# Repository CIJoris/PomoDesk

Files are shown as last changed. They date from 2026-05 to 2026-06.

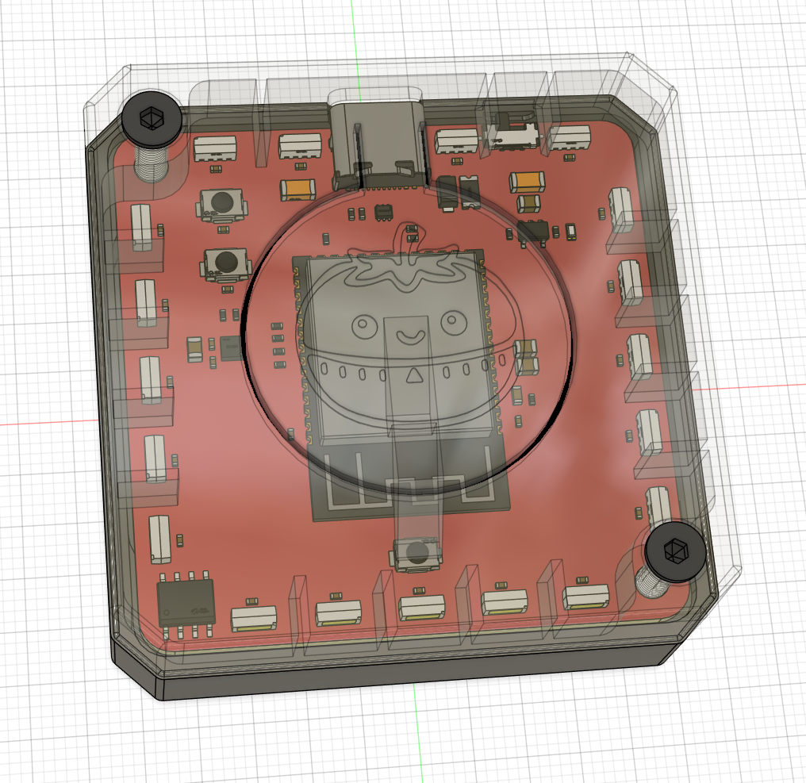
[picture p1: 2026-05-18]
Hardware/Enclosure/Fusion360_XVKBeL06ep.png

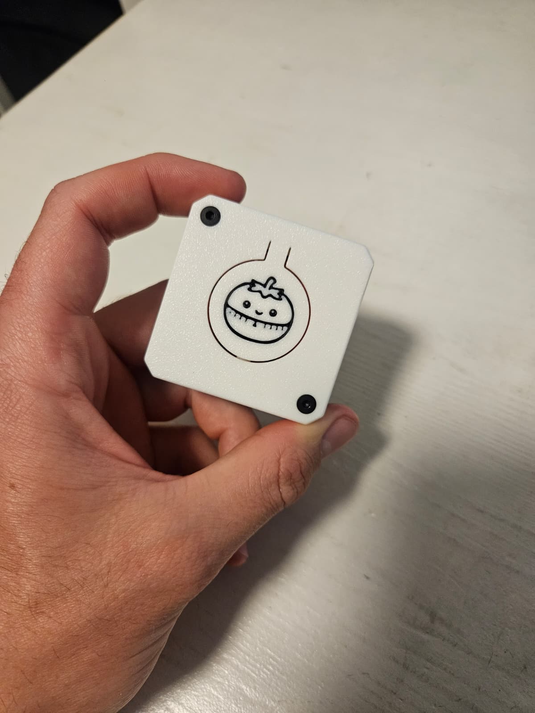
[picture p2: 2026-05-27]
Photos/pomo-desk-hand.jpeg

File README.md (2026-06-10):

# PomoDesk - Physical Pomodoro Timer

pomo-desk-banner-image

**ESP32-based physical Pomodoro timer with local configuration options**

Designing PCB's, creating or adjusting schematics, doing layout, all these tasks put me in this trance, this FLOW, as some would say.
I've learned it's a gift, not available for everyone, to reach this kind of state. But, there is a small downside to this. This flow-state you have to manage with caution.

To not forget about life, you need something to wake you from this flow every now and then.
The perfect way to do this, for me personally, is to have a Pomodoro timer.

**Focus for 45 minutes, break for 5, then continue.**

WhatsApp Image 2026-05-29 at 22 05 28

I wanted to create a Pomodoro timer that's not some app counting down on my screen.
It needs to be physical, elegant and as unobtrusive as possible, only showing itself when it's time to break.

**States & Workflow**

PomoDesk follows the Pomodoro technique: a simple productivity method that alternates periods of focused work with short breaks to help maintain concentration and prevent burnout.

The device has three states:

* Idle (Orange) – Ready to start a new session.
* Focus (Green) – A dedicated work period where distractions are minimized and attention stays on a single task.
* Break (Red) – A short recovery period to step away, stretch, grab a drink, or simply reset before the next focus session.

WhatsApp Image 2026-05-30 at 12 02 46

By default, PomoDesk uses a 45-minute focus period followed by a 5-minute break, after which it returns to Idle and waits for the next session. All timings can be customized through the built-in configuration webserver.

**Power**

PomoDesk is powered through a standard USB-C connection and is designed to run continuously on any 5V USB power source.

WhatsApp Image 2026-05-29 at 22 11 27 

It can be powered from:

* A USB wall adapter
* A laptop or desktop USB port
* A USB hub or monitor with USB output
* A power bank for portable use

The ESP32-S3 and LED ring have been optimized for low power consumption, and the built-in ECO mode and deep sleep functionality help minimize energy usage when the device is idle.

This first iteration is far from perfect, but it's a start.

pomo-desk-orange

---

# V1.1 - Local Configuration Webserver

Version 1.1 adds a local configuration mode directly on the ESP32-S3.

By pressing and holding the button, PomoDesk can start its own Wi-Fi configuration portal. From there, the timer can be customized without needing to reflash the firmware.

### Button controls

WhatsApp Image 2026-05-31 at 11 31 27

* Short press: step through states
* Hold 1.5 seconds, release: enter or exit config mode
* Hold 3 seconds, release: toggle RGB cycle mode
* Hold 6 seconds, release: go to sleep

### Config mode

When config mode is active, PomoDesk creates its own Wi-Fi network:

```text
Wi-Fi: PomoDesk-Config
Password: pomodesk
Open: http://pomodesk.local
Fallback: http://10.10.10.1
```

### Added in v1.1 
* Local Wi-Fi configuration webserver
* Adjustable state colors
* Adjustable Focus, Break and Idle timings
* Multiple LED transition modes
* Adjustable transition speed
* Brightness control
* RGB cycle mode
* ECO brightness mode
* Reset to default settings
* Config mode with blue LED indication
* Deep sleep mode
* Wake-up by button press
* Settings saved to ESP32 memory

---

*Feel free to send me constructive criticism or things you would like me to implement, or even if you would like to help me develop this system!*

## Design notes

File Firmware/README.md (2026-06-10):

# PomoDesk - Physical Pomodoro Timer
**ESP32-based Pomodoro timer with API options**

## Getting Started

### Requirements

Before compiling and uploading the firmware, make sure the following is installed:

* Arduino IDE 2.x
* Adafruit NeoPixel library
* ESP32 Boards Package by Espressif Systems

### Install ESP32 Board Support

In Arduino IDE:

1. Open **File → Preferences**
2. Add the following URL to **Additional Boards Manager URLs**:

```text
https://espressif.github.io/arduino-esp32/package_esp32_index.json
```

3. Open **Tools → Board → Boards Manager**
4. Search for **ESP32**
5. Install **ESP32 by Espressif Systems**

### Install Required Libraries

Open **Tools → Manage Libraries** and install:

* Adafruit NeoPixel

### Board Configuration

Select the following settings before uploading:

* Board: **ESP32S3 Dev Module**
* USB CDC On Boot: **Enabled**
* Upload Mode: **UART0 / Default**
* Flash Mode: **QIO 80MHz**
* Partition Scheme: **Default 4MB with SPIFFS** (or larger if desired)

### Uploading

1. Connect the ESP32-S3 via USB-C.
2. Select the correct COM port in Arduino IDE.
3. Compile and upload the firmware.
4. Open the Serial Monitor if debugging is required.

After flashing, the device will boot directly into the **Idle** state and is ready to use.

# V1.0:

## Features

- Physical one-button control
- Idle, Focus, Break states
- Multiple LED transition modes
- Settings saved in ESP32 Preferences memory

# V1.1:

**Now with a configurable NeoPixel LED ring and a built-in local configuration webserver.**

## Features

- Config state
- Adjustable state colors
- Adjustable Focus, Break, and Idle times
- Adjustable transition speed
- Brightness control with ECO mode
- RGB cycle mode
- Local Wi-Fi configuration portal
- Deep sleep mode with button wake-up

## Controls

- Short press: step through states
- Hold 1.5 seconds, release: enter or exit config mode
- Hold 3 seconds, release: toggle RGB cycle mode
- Hold 6 seconds, release: go to sleep

## States

PomoDesk follows the Pomodoro technique: alternating focused work sessions with short breaks to maintain concentration and prevent mental fatigue.

The device has three primary states:

* **Idle (Orange)** – Ready to start a new session.
* **Focus (Green)** – Active work period.
* **Break (Red)** – Short recovery period.

By default, PomoDesk uses a **45-minute Focus session** followed by a **5-minute Break**. These timings can be customized through the configuration webserver in V1.1.

## Config Mode

When config mode is active, PomoDesk creates its own Wi-Fi network:

- Wi-Fi: `PomoDesk-Config`
- Password: `pomodesk`
- Open: `http://pomodesk.local`
- Fallback: `http://10.10.10.1`

The web interface lets you customize colors, timers, transitions, speed, brightness, reset defaults, exit config mode, or put the device to sleep.

---

*Feel free to send me constructive criticism or things you would like me to implement, or even if you would like to help me develop this system!*

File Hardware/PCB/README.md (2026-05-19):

# PomoDesk - Physical Pomodoro Timer
**ESP32-based Pomodoro timer with API options**

V1.0 notes:
---

- the whole board is getting a bit warm
- on/off button is hard to reach, might as well remove
- data pin for LEDs needs to be higher voltage, use a levelshifter like: 74AHCT1G125, 74AHCT125, SN74AHCT1G125, SN74AHCT125
- power led connected to IO18 is not standard ON so the pin must be high/mid when the ESP is not programmed
- the corners don't have LEDs, which is not pretty
- startup surge causes USB hub to disconnect shortly -> Add LED power switching:
USB 5V → P-MOSFET/load switch → LED 5V
ESP GPIO → enable LED power after boot 

---

*Feel free to send me constructive criticism or things you would like me to implement, or even if you would like to help me develop this system!*

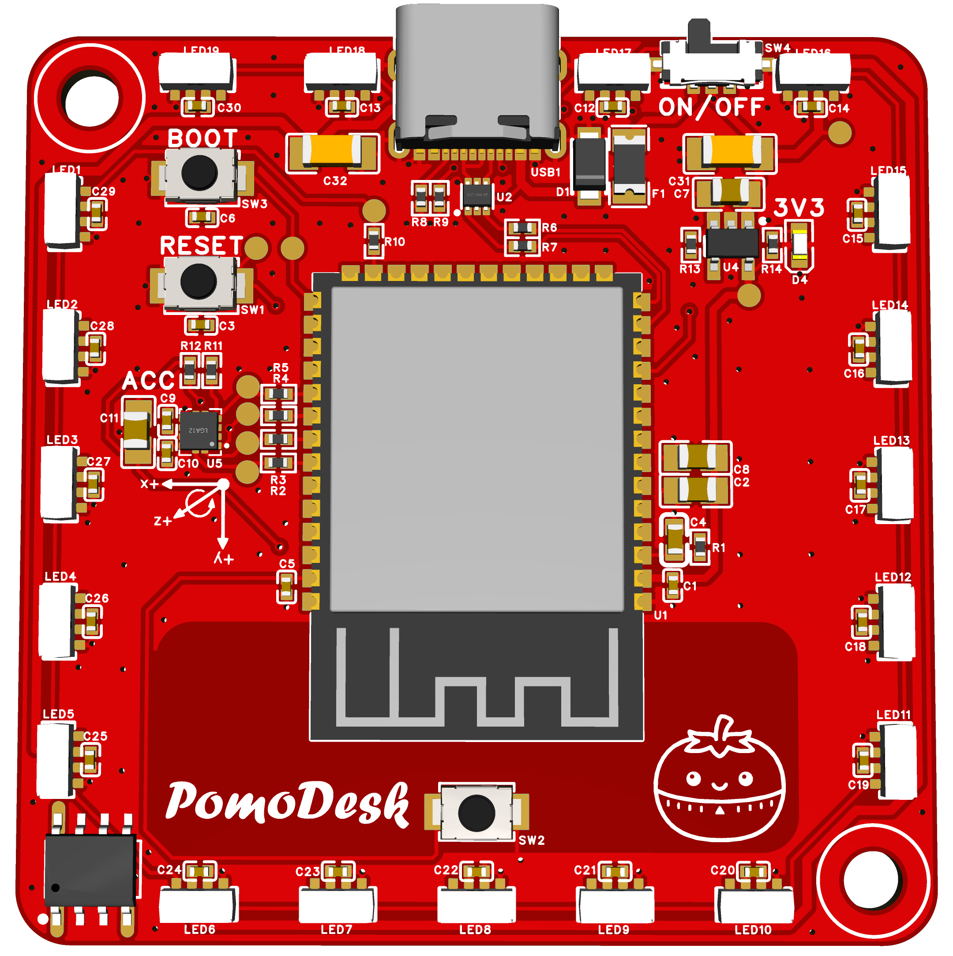
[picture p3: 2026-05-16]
Hardware/PCB/3D_PCB_V1.0_2026-05-16-top.png

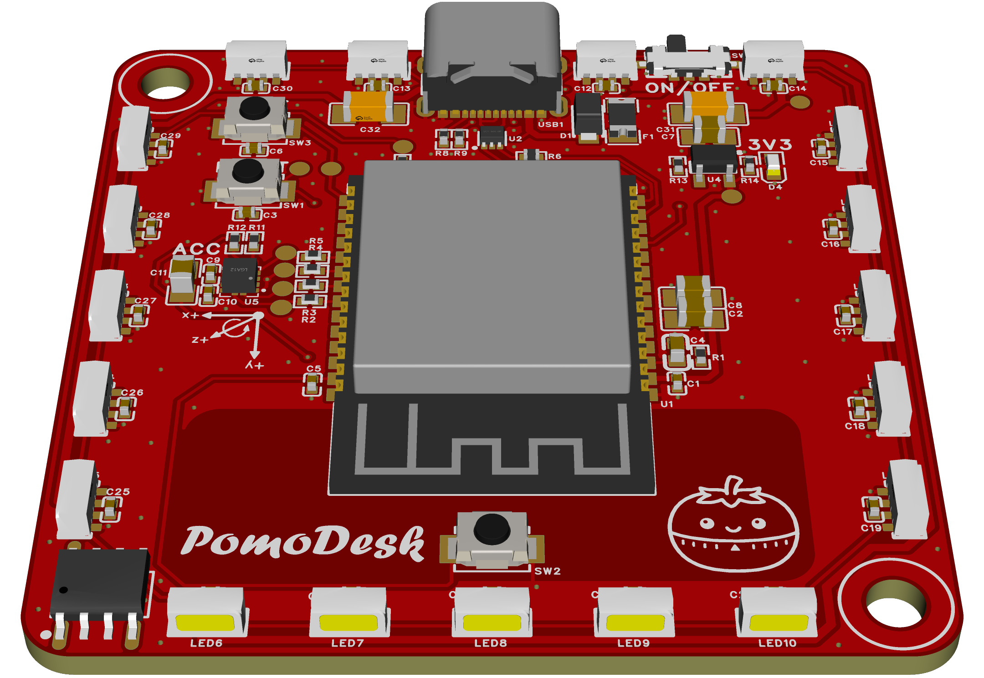
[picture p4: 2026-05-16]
Hardware/PCB/3D_PCB_V1.0_2026-05-16.png

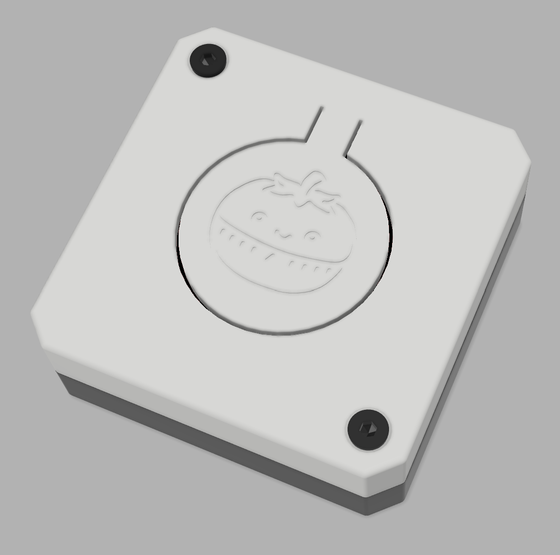
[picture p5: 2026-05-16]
Hardware/Enclosure/pomodesk-render-v1.0.png

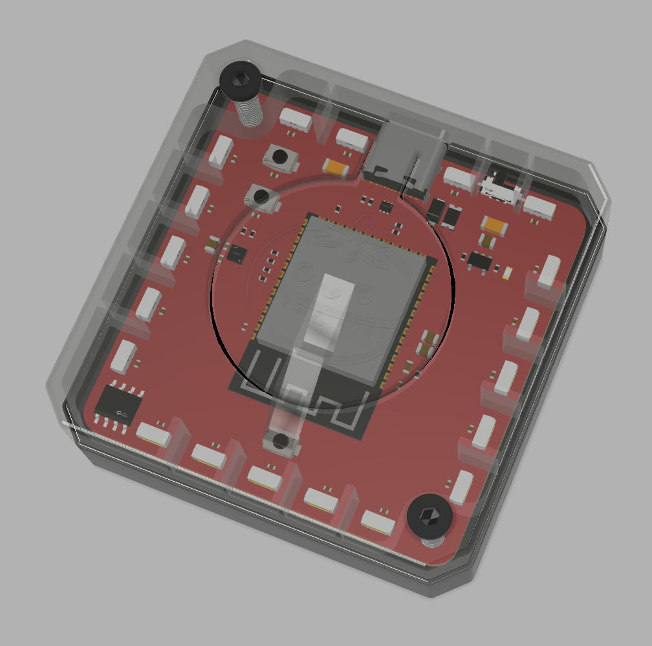
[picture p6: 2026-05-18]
Hardware/Enclosure/Fusion360_l14pNBqwwQ.png

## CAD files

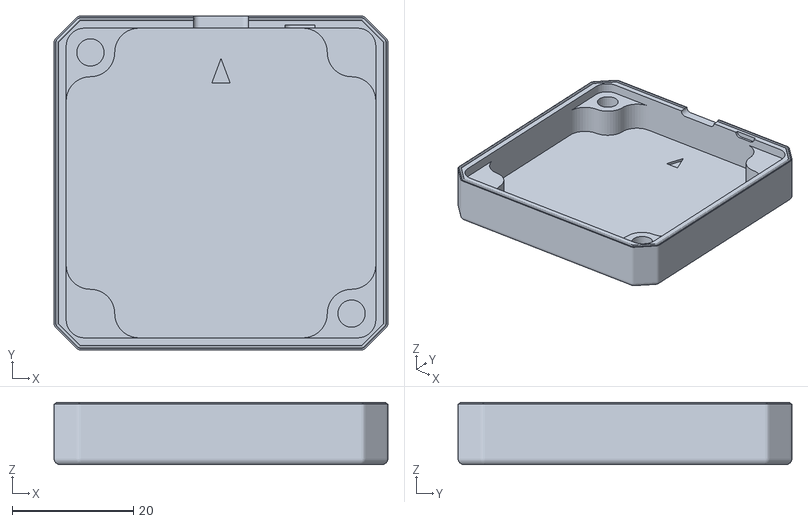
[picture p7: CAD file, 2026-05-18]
Hardware/Enclosure/pomo-desk-bottom-v4.stl
55.0 x 55.0 x 10.2

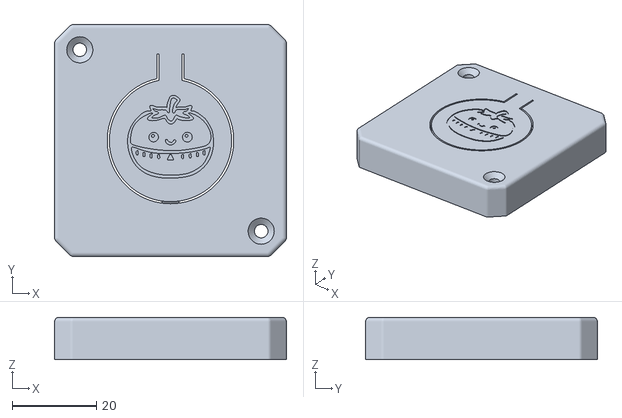
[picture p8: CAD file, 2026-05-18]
Hardware/Enclosure/pomo-desk-top-v4.stl
55.0 x 55.0 x 10.0

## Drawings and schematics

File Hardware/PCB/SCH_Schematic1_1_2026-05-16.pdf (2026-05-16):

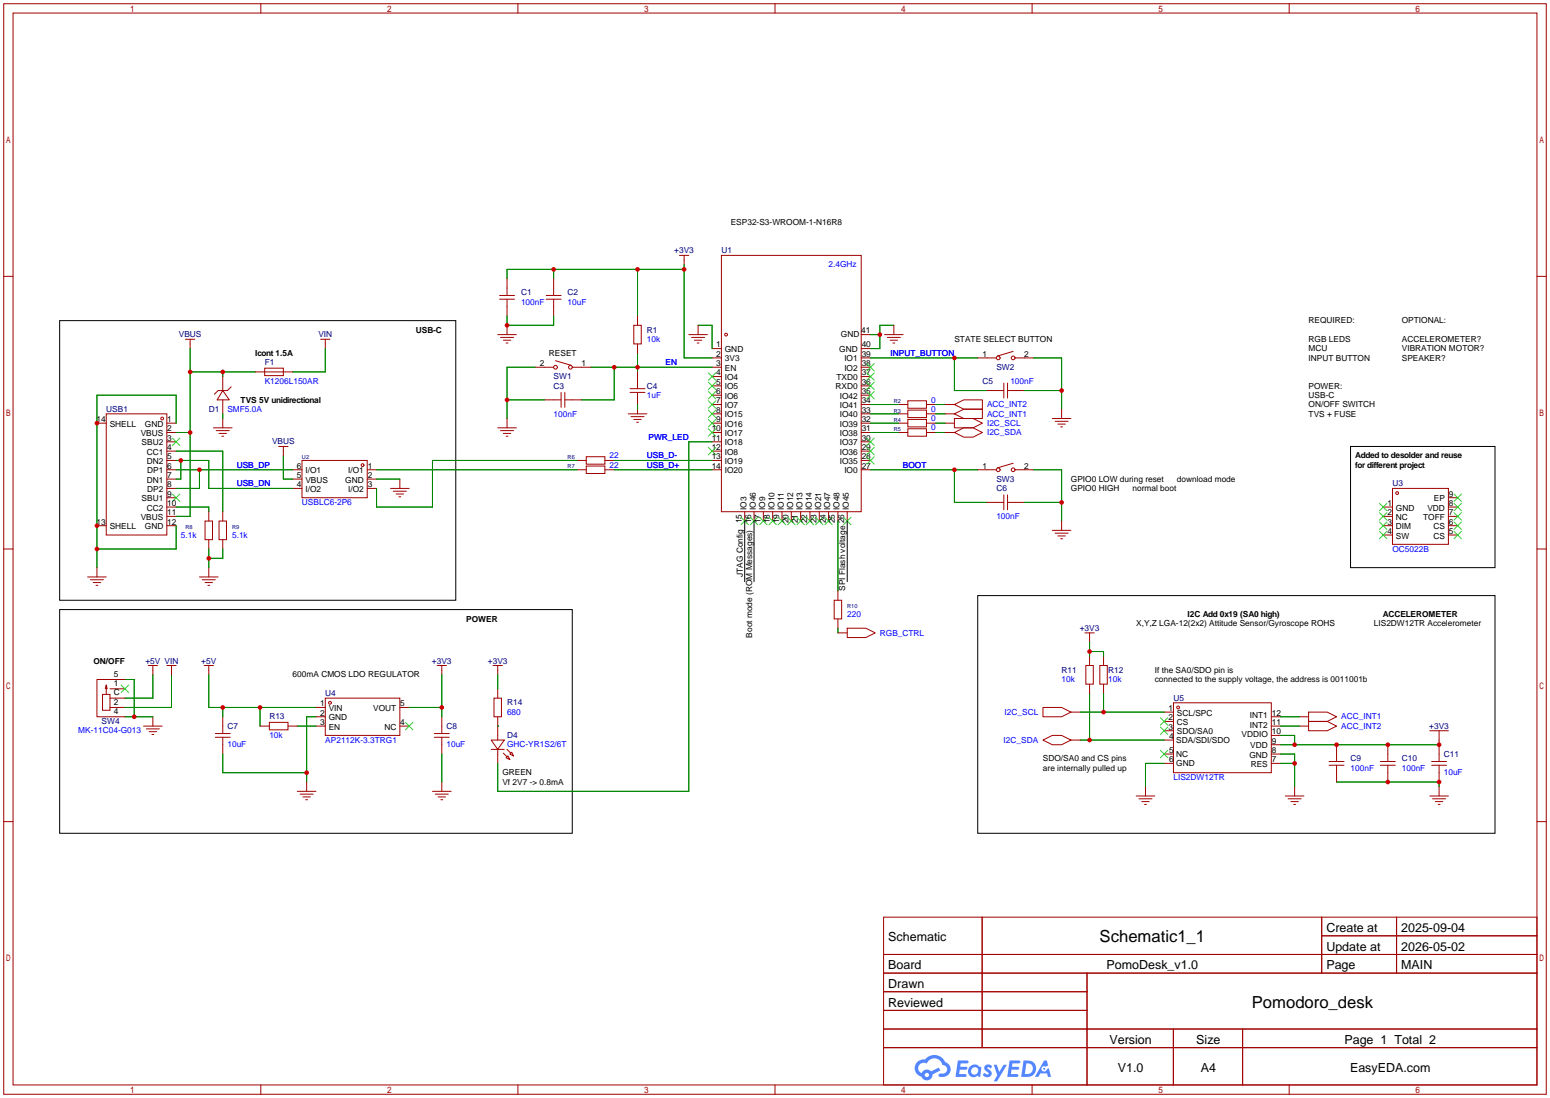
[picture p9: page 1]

Added to desolder and reuse
for different project

GPIO0 LOW during reset download mode
GPIO0 HIGH normal boot

Boot mode (ROM Messages)

X,Y,Z LGA-12(2x2) Attitude Sensor/Gyroscope ROHS

If the SA0/SDO pin is
connected to the supply voltage, the address is 0011001b
SCL/SPC 1
SDO/SA0 3
SDA/SDI/SDO 4
GND 6
LIS2DW12TR

SDO/SA0 and CS pins
are internally pulled up

Schematic | Schematic1_1 | Create at | 2025-09-04

Update at | 2026-05-02

Board | PomoDesk_v1.0 | Page | MAIN
Drawn | | Pomodoro_desk
Reviewed

Version | Size | Page 1 Total 2
V1.0 | A4 | EasyEDA.com

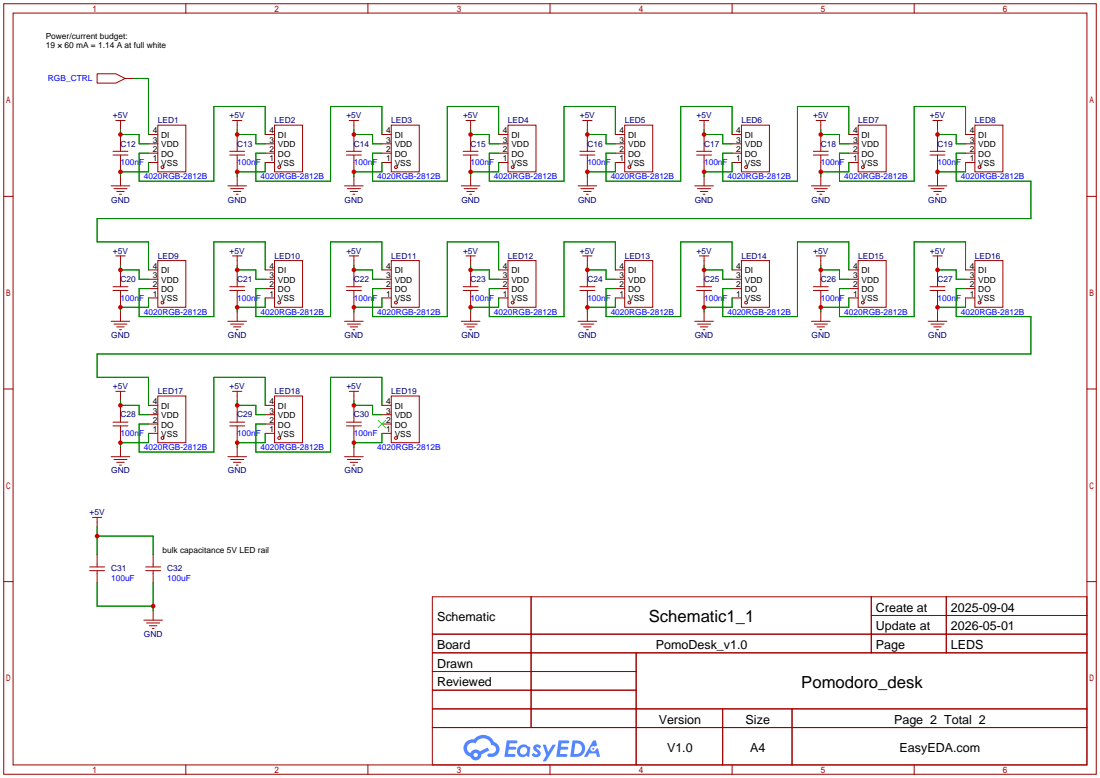
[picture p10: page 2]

Power/current budget:
19 × 60 mA = 1.14 A at full white

Schematic | Schematic1_1 | Create at | 2025-09-04

Update at | 2026-05-01

Board | PomoDesk_v1.0 | Page | LEDS
Drawn | | Pomodoro_desk
Reviewed

Version | Size | Page 2 Total 2
V1.0 | A4 | EasyEDA.com

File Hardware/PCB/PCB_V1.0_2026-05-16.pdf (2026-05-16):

# BOOT

# ON/OFF

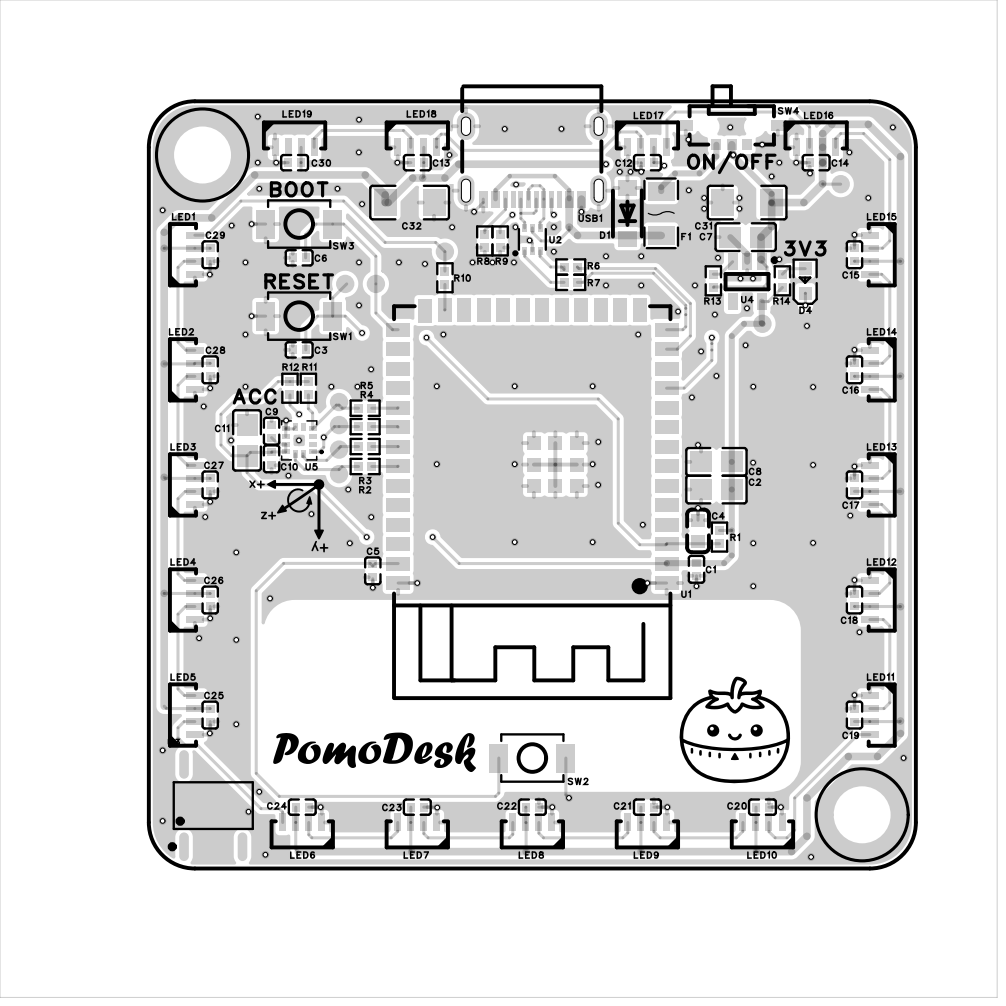
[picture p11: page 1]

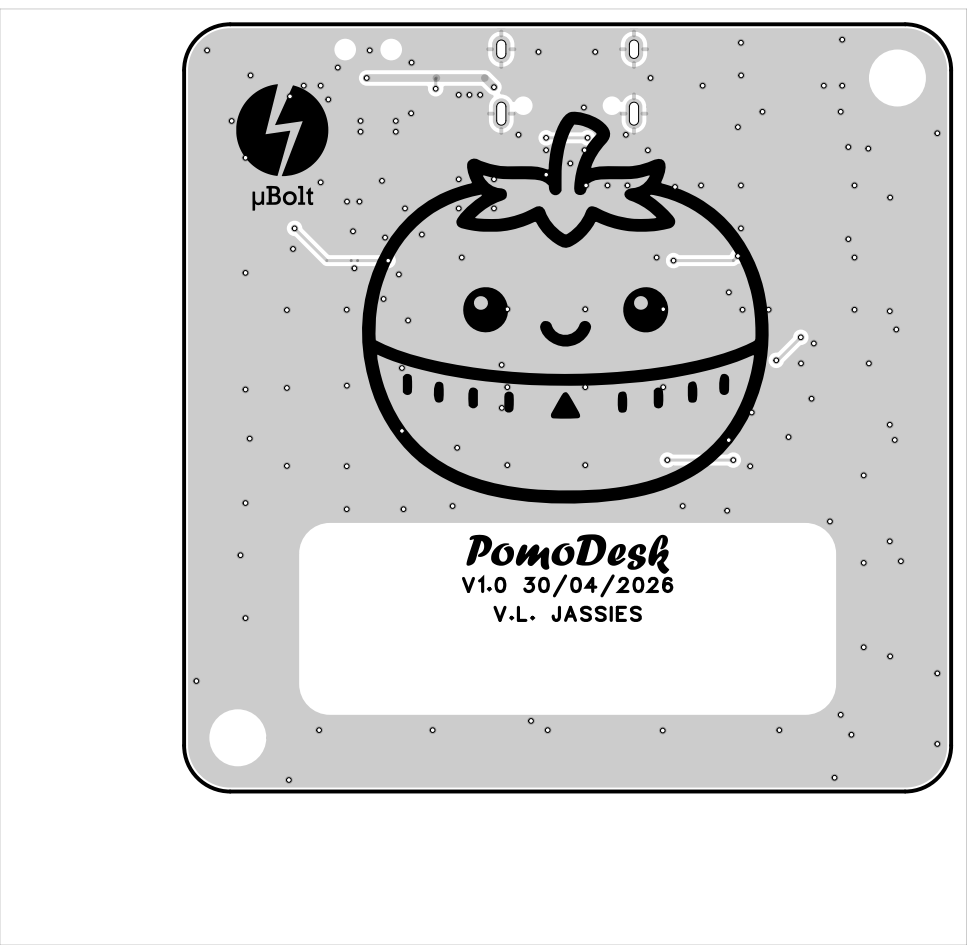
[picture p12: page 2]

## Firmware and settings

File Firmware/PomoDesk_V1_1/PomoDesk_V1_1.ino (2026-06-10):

#include <Arduino.h>
#include <Adafruit_NeoPixel.h>
#include <WiFi.h>
#include <WebServer.h>
#include <Preferences.h>
#include <DNSServer.h>
#include <ESPmDNS.h>
#include <esp_bt.h>
#include <esp_sleep.h>
#include <driver/rtc_io.h>

// --- Pins ---
const int BTN_STATE = 1;
const int LED_DATA  = 48;
const int PWR_LED   = 18;

// --- LEDs ---
const int NUM_LEDS = 19;
Adafruit_NeoPixel strip(NUM_LEDS, LED_DATA, NEO_GRB + NEO_KHZ800);

// --- WiFi / Webserver ---
WebServer server(80);
DNSServer dnsServer;
Preferences prefs;

const char* AP_SSID = "PomoDesk-Config";
const char* AP_PASS = "pomodesk";

IPAddress apIP(10, 10, 10, 1);
IPAddress gateway(10, 10, 10, 1);
IPAddress subnet(255, 255, 255, 0);

bool configMode = false;

// --- Defaults ---
const uint32_t WORK_MS_DEFAULT     = 45UL * 60UL * 1000UL;
const uint32_t BREAK_MS_DEFAULT    = 5UL  * 60UL * 1000UL;
const uint32_t IDLE_LED_MS_DEFAULT = 10UL * 60UL * 1000UL;

const uint32_t CONFIG_TIME_MS  = 1500;
const uint32_t RAINBOW_TIME_MS = 3000;
const uint32_t OFF_TIME_MS     = 6000;

const uint32_t DEFAULT_IDLE_RAW   = 0xFF5000;
const uint32_t DEFAULT_WORK_RAW   = 0x00FF00;
const uint32_t DEFAULT_BREAK_RAW  = 0xFF0000;
const uint32_t DEFAULT_CONFIG_RAW = 0x0078FF;

// --- Settings ---
uint32_t workMs;
uint32_t breakMs;
uint32_t idleLedMs;
uint8_t brightness = 150;

// --- Transitions ---
enum Transition {
  SET_RING,
  RUNNING_LIGHT,
  RUNNING_FILL,
  RUNNING_LIGHT_CLEAR,
  FADE
};

Transition transition = RUNNING_FILL;
uint16_t transitionDelayMs = 40;

// --- States ---
enum State { IDLE, WORK, BREAK };
State state = IDLE;

uint32_t stateStartMs = 0;
bool idleLedsOff = false;
bool rainbowMode = false;
uint8_t rainbowOffset = 0;
uint32_t lastRainbowStepMs = 0;

// --- Colors ---
uint32_t COLOR_IDLE;
uint32_t COLOR_WORK;
uint32_t COLOR_BREAK;
uint32_t COLOR_CONFIG;

uint32_t currentColor = 0;

// --- Forward declarations ---
void stopConfigServer();
void powerOffDevice();
void handleExitConfig();
void handleSleep();
void startRainbowMode();
void stopRainbowMode();

// --- Helpers ---
uint32_t rawToNeo(uint32_t raw) {
  uint8_t r = (raw >> 16) & 0xFF;
  uint8_t g = (raw >> 8) & 0xFF;
  uint8_t b = raw & 0xFF;
  return strip.Color(r, g, b);
}

String colorToHex(uint32_t color) {
  char hex[8];
  sprintf(hex, "#%02X%02X%02X",
          (uint8_t)(color >> 16),
          (uint8_t)(color >> 8),
          (uint8_t)color);
  return String(hex);
}

uint32_t hexToColor(String hex) {
  hex.replace("#", "");
  uint32_t value = strtoul(hex.c_str(), nullptr, 16);
  return rawToNeo(value);
}

uint16_t transitionDelay() {
  return constrain(transitionDelayMs, 5, 500);
}

uint32_t wheel(uint8_t wheelPos) {
  wheelPos = 255 - wheelPos;

  if (wheelPos < 85) {
    return strip.Color(255 - wheelPos * 3, 0, wheelPos * 3);
  }

  if (wheelPos < 170) {
    wheelPos -= 85;
    return strip.Color(0, wheelPos * 3, 255 - wheelPos * 3);
  }

  wheelPos -= 170;
  return strip.Color(wheelPos * 3, 255 - wheelPos * 3, 0);
}

// --- LED functions ---
void setRing(uint32_t color) {
  strip.setBrightness(brightness);

  for (int i = 0; i < NUM_LEDS; i++) {
    strip.setPixelColor(i, color);
  }

  strip.show();
  currentColor = color;
}

void allLedsOff() {
  strip.clear();
  strip.show();
  currentColor = 0;
}

void runningLights(uint32_t color) {
  allLedsOff();

  for (int i = 0; i < NUM_LEDS; i++) {
    strip.clear();
    strip.setPixelColor(i, color);
    strip.setPixelColor((i - 1 + NUM_LEDS) % NUM_LEDS, color);
    strip.setPixelColor((i - 2 + NUM_LEDS) % NUM_LEDS, color);
    strip.show();
    delay(transitionDelay());
  }

  setRing(color);
}

void runningFill(uint32_t color) {
  allLedsOff();

  for (int i = 0; i < NUM_LEDS; i++) {
    strip.setPixelColor(i, color);
    strip.show();
    delay(transitionDelay());
  }

  currentColor = color;
}

void runningFillClear(uint32_t color) {
  runningFill(color);
  delay(transitionDelay());

  for (int i = 0; i < NUM_LEDS; i++) {
    strip.setPixelColor(i, 0);
    strip.show();
    delay(transitionDelay());
  }

  currentColor = 0;
}

uint8_t blend8(uint8_t from, uint8_t to, uint8_t step, uint8_t steps) {
  return from + ((int16_t)(to - from) * step) / steps;
}

void fadeToColor(uint32_t targetColor) {
  uint8_t r1 = (currentColor >> 16) & 0xFF;
  uint8_t g1 = (currentColor >> 8) & 0xFF;
  uint8_t b1 = currentColor & 0xFF;

  uint8_t r2 = (targetColor >> 16) & 0xFF;
  uint8_t g2 = (targetColor >> 8) & 0xFF;
  uint8_t b2 = targetColor & 0xFF;

  const uint8_t fadeSteps = 40;

  for (uint8_t step = 0; step <= fadeSteps; step++) {
    uint32_t c = strip.Color(
      blend8(r1, r2, step, fadeSteps),
      blend8(g1, g2, step, fadeSteps),
      blend8(b1, b2, step, fadeSteps)
    );

    for (int i = 0; i < NUM_LEDS; i++) {
      strip.setPixelColor(i, c);
    }

    strip.show();
    delay(transitionDelay());
  }

  currentColor = targetColor;
}

void applyTransition(uint32_t color) {
  strip.setBrightness(brightness);

  switch (transition) {
    case SET_RING:
      setRing(color);
      break;

    case RUNNING_LIGHT:
      runningLights(color);
      break;

    case RUNNING_FILL:
      runningFill(color);
      break;

    case RUNNING_LIGHT_CLEAR:
      runningFillClear(color);
      break;

    case FADE:
      fadeToColor(color);
      break;
  }
}

void updateRainbowCycle() {
  const uint32_t now = millis();

  if (now - lastRainbowStepMs < 30) {
    return;
  }

  lastRainbowStepMs = now;
  strip.setBrightness(brightness);

  for (int i = 0; i < NUM_LEDS; i++) {
    uint8_t wheelPos = (i * 256 / NUM_LEDS + rainbowOffset) & 0xFF;
    strip.setPixelColor(i, wheel(wheelPos));
  }

  strip.show();
  rainbowOffset++;
}

// --- Settings ---
void loadSettings() {
  prefs.begin("pomodesk", true);

  workMs = prefs.getUInt("workMs", WORK_MS_DEFAULT);
  breakMs = prefs.getUInt("breakMs", BREAK_MS_DEFAULT);
  idleLedMs = prefs.getUInt("idleMs", IDLE_LED_MS_DEFAULT);

  brightness = prefs.getUChar("bright", 150);
  transitionDelayMs = prefs.getUShort("delay", 40);
  transition = (Transition)prefs.getUChar("trans", RUNNING_FILL);

  COLOR_IDLE   = prefs.getUInt("idleColor", rawToNeo(DEFAULT_IDLE_RAW));
  COLOR_WORK   = prefs.getUInt("workColor", rawToNeo(DEFAULT_WORK_RAW));
  COLOR_BREAK  = prefs.getUInt("breakColor", rawToNeo(DEFAULT_BREAK_RAW));
  COLOR_CONFIG = prefs.getUInt("configColor", rawToNeo(DEFAULT_CONFIG_RAW));

  prefs.end();
}

void saveSettings() {
  prefs.begin("pomodesk", false);

  prefs.putUInt("workMs", workMs);
  prefs.putUInt("breakMs", breakMs);
  prefs.putUInt("idleMs", idleLedMs);

  prefs.putUChar("bright", brightness);
  prefs.putUShort("delay", transitionDelayMs);
  prefs.putUChar("trans", transition);

  prefs.putUInt("idleColor", COLOR_IDLE);
  prefs.putUInt("workColor", COLOR_WORK);
  prefs.putUInt("breakColor", COLOR_BREAK);
  prefs.putUInt("configColor", COLOR_CONFIG);

  prefs.end();
}

void resetSettings() {
  workMs = WORK_MS_DEFAULT;
  breakMs = BREAK_MS_DEFAULT;
  idleLedMs = IDLE_LED_MS_DEFAULT;

  brightness = 150;
  transitionDelayMs = 40;
  transition = RUNNING_FILL;

  COLOR_IDLE   = rawToNeo(DEFAULT_IDLE_RAW);
  COLOR_WORK   = rawToNeo(DEFAULT_WORK_RAW);
  COLOR_BREAK  = rawToNeo(DEFAULT_BREAK_RAW);
  COLOR_CONFIG = rawToNeo(DEFAULT_CONFIG_RAW);

  saveSettings();
}

// --- State logic ---
void enterState(State s) {
  if (configMode) return;

  rainbowMode = false;

  state = s;
  stateStartMs = millis();
  idleLedsOff = false;

  if (state == IDLE) {
    applyTransition(COLOR_IDLE);
  }
  else if (state == WORK) {
    applyTransition(COLOR_WORK);
  }
  else if (state == BREAK) {
    applyTransition(COLOR_BREAK);
  }
}

void nextState() {
  if (configMode) return;

  if (state == IDLE) {
    enterState(WORK);
  }
  else if (state == WORK) {
    enterState(BREAK);
  }
  else {
    enterState(IDLE);
  }
}

// --- Web UI ---
String htmlPage() {
  String html = R"rawliteral(
<!DOCTYPE html>
<html>
<head>
<meta name="viewport" content="width=device-width, initial-scale=1">
<title>PomoDesk Config</title>

<style>
body {
  margin: 0;
  font-family: Arial, sans-serif;
  background: radial-gradient(circle at top, #1b1b1b, #050505);
  color: #eee;
  letter-spacing: 2px;
}

.wrap {
  max-width: 760px;
  margin: auto;
  padding: 36px 24px;
}

h1 {
  text-align: center;
  color: #ff9b54;
  font-weight: 300;
  letter-spacing: 10px;
}

h2 {
  text-align: center;
  color: #aaa;
  font-weight: 300;
  font-size: 14px;
  margin-bottom: 40px;
}

.card {
  border: 1px solid #333;
  background: rgba(255,255,255,0.035);
  padding: 24px;
  margin-bottom: 22px;
  border-radius: 18px;
  box-shadow: 0 0 40px rgba(255,120,60,0.08);
}

label {
  color: #ff9b54;
  font-size: 13px;
}

input, select {
  padding: 12px;
  border-radius: 10px;
  border: 1px solid #333;
  background: #111;
  color: #eee;
  font-size: 15px;
  box-sizing: border-box;
}

select {
  width: 100%;
  margin-top: 8px;
}

input[type=number] {
  width: 62px;
  text-align: center;
}

input[type=range] {
  width: 100%;
}

button {
  border: 0;
  border-radius: 12px;
  background: #ff6b2b;
  color: #111;
  font-weight: bold;
  letter-spacing: 2px;
}

.color-row {
  display: grid;
  grid-template-columns: 1fr auto;
  align-items: center;
  gap: 10px;
  margin-top: 18px;
}

.color-actions {
  justify-self: end;
  display: flex;
  align-items: end;
  gap: 10px;
}

.swatch {
  width: 44px;
  height: 44px;
  border-radius: 10px;
  border: 1px solid #444;
  cursor: pointer;
}

.custom-wrap {
  display: flex;
  flex-direction: column;
  align-items: center;
  gap: 4px;
}

.custom-label {
  font-size: 9px;
  color: #aaa;
  line-height: 1.1;
  text-align: center;
  letter-spacing: 1px;
}

.custom-color {
  width: 44px;
  height: 44px;
  padding: 2px;
  border-radius: 10px;
  border: 1px solid #444;
  background: #111;
}

.time-row {
  display: grid;
  grid-template-columns: 1fr 40px 62px 40px;
  align-items: center;
  gap: 8px;
  margin-top: 18px;
}

.time-row label {
  justify-self: start;
}

.step-btn {
  width: 40px;
  height: 40px;
  padding: 0;
  font-size: 20px;
  line-height: 40px;
}

.setting-row {
  margin-top: 18px;
}

.inline-control {
  display: grid;
  grid-template-columns: 1fr auto auto;
  align-items: center;
  gap: 10px;
  margin-top: 8px;
}

.inline-control input {
  width: 100%;
}

.preset-btn {
  height: 42px;
  padding: 0 14px;
  font-size: 11px;
}

.brightness-row {
  display: grid;
  grid-template-columns: 1fr;
  gap: 12px;
  margin-top: 8px;
}

.brightness-buttons {
  display: grid;
  grid-template-columns: 1fr 1fr;
  gap: 12px;
}

.action-row {
  display: grid;
  grid-template-columns: 1fr 1fr;
  gap: 12px;
  margin-top: 22px;
}

.save-btn,
.reset,
.exit-btn,
.sleep-btn {
  width: 100%;
  padding: 15px;
  margin: 0;
}

.reset,
.exit-btn {
  background: transparent;
  color: #ff6b2b;
  border: 1px solid #ff6b2b;
}

.sleep-btn {
  background: #222;
  color: #ff6b2b;
  border: 1px solid #333;
}

.hint {
  color: #777;
  font-size: 12px;
  line-height: 1.6;
  margin-top: 12px;
  letter-spacing: 1px;
}

.footer {
  text-align: center;
  color: #777;
  margin-top: 36px;
  font-size: 12px;
}
</style>
</head>

<body>
<div class="wrap">
<h1>POMODESK</h1>
<h2>CONFIGURATION WEBSERVER</h2>

<form id="configForm" action="/save" method="POST">

<div class="card">
  <div class="color-row">
    <label>Idle color</label>
    <div class="color-actions">
      <button class="swatch" type="button" style="background:#FF5000" onclick="setColor('idleColor', '#FF5000', 'idle')"></button>
      <div class="custom-wrap">
        <span class="custom-label">Custom</span>
        <input class="custom-color" type="color" id="idleColor" name="idleColor" value="%IDLE_COLOR%" onchange="customColorChosen('idleColor', 'idle')">
      </div>
    </div>
  </div>

  <div class="color-row">
    <label>Focus color</label>
    <div class="color-actions">
      <button class="swatch" type="button" style="background:#00FF00" onclick="setColor('workColor', '#00FF00', 'work')"></button>
      <div class="custom-wrap">
        <span class="custom-label">Custom</span>
        <input class="custom-color" type="color" id="workColor" name="workColor" value="%WORK_COLOR%" onchange="customColorChosen('workColor', 'work')">
      </div>
    </div>
  </div>

  <div class="color-row">
    <label>Break color</label>
    <div class="color-actions">
      <button class="swatch" type="button" style="background:#FF0000" onclick="setColor('breakColor', '#FF0000', 'break')"></button>
      <div class="custom-wrap">
        <span class="custom-label">Custom</span>
        <input class="custom-color" type="color" id="breakColor" name="breakColor" value="%BREAK_COLOR%" onchange="customColorChosen('breakColor', 'break')">
      </div>
    </div>
  </div>

  <div class="color-row">
    <label>Config mode color</label>
    <div class="color-actions">
      <button class="swatch" type="button" style="background:#0078FF" onclick="setColor('configColor', '#0078FF', 'config')"></button>
      <div class="custom-wrap">
        <span class="custom-label">Custom</span>
        <input class="custom-color" type="color" id="configColor" name="configColor" value="%CONFIG_COLOR%" onchange="customColorChosen('configColor', 'config')">
      </div>
    </div>
  </div>
</div>

<div class="card">
  <div class="time-row">
    <label>Focus time</label>
    <button class="step-btn" type="button" onclick="stepValue('workMin', -1)">-</button>
    <input id="workMin" type="number" name="workMin" min="1" max="99" value="%WORK_MIN%">
    <button class="step-btn" type="button" onclick="stepValue('workMin', 1)">+</button>
  </div>

  <div class="time-row">
    <label>Break time</label>
    <button class="step-btn" type="button" onclick="stepValue('breakMin', -1)">-</button>
    <input id="breakMin" type="number" name="breakMin" min="1" max="99" value="%BREAK_MIN%">
    <button class="step-btn" type="button" onclick="stepValue('breakMin', 1)">+</button>
  </div>

  <div class="time-row">
    <label>Idle LED timeout</label>
    <button class="step-btn" type="button" onclick="stepValue('idleMin', -1)">-</button>
    <input id="idleMin" type="number" name="idleMin" min="1" max="99" value="%IDLE_MIN%">
    <button class="step-btn" type="button" onclick="stepValue('idleMin', 1)">+</button>
  </div>
</div>

<div class="card">
  <div class="setting-row">
    <label>Transition</label>
    <select name="transition" onchange="previewTransition('config')">
      <option value="0" %T0%>Set ring</option>
      <option value="1" %T1%>Running light</option>
      <option value="2" %T2%>Running fill</option>
      <option value="3" %T3%>Running fill clear</option>
      <option value="4" %T4%>Fade</option>
    </select>
  </div>

  <div class="setting-row">
    <label>Transition speed, ms</label>
    <div class="inline-control">
      <input id="delayInput" type="number" name="delay" min="5" max="500" value="%DELAY%" onchange="previewTransition('config')">
      <button class="preset-btn" type="button" onclick="setDelay(40)">NORMAL</button>
      <button class="preset-btn" type="button" onclick="setDelay(80)">GENTLE</button>
    </div>
  </div>

  <div class="setting-row">
    <label>Brightness / ECO mode</label>
    <div class="brightness-row">
      <input id="brightnessInput" type="range" name="brightness" min="5" max="255" value="%BRIGHTNESS%" oninput="previewTransition('config')">
      <div class="brightness-buttons">
        <button class="preset-btn" type="button" onclick="setBrightnessNormal()">NORMAL</button>
        <button class="preset-btn" type="button" onclick="setEco()">ECO</button>
      </div>
    </div>
    <div class="hint">Lower brightness reduces current consumption.</div>
  </div>
</div>

<div class="action-row">
  <button class="reset" type="submit" formaction="/reset" formmethod="POST">RESET TO DEFAULT</button>
  <button class="save-btn" type="submit">SAVE SETTINGS</button>
</div>

<div class="action-row">
  <button class="exit-btn" type="button" onclick="location.href='/exit'">EXIT CONFIG</button>
  <button class="sleep-btn" type="button" onclick="location.href='/sleep'">GO TO SLEEP</button>
</div>

</form>

<div class="footer">
  PHYSICAL POMODORO TIMER<br>
  OPEN: pomodesk.local OR 10.10.10.1
</div>
</div>

<script>
function stepValue(id, step) {
  const input = document.getElementById(id);
  let value = parseInt(input.value || "1");
  value += step;
  value = Math.max(1, Math.min(99, value));
  input.value = value;
}

function setColor(id, value, state) {
  const input = document.getElementById(id);
  input.value = value;
  previewTransition(state);
}

function customColorChosen(id, state) {
  const input = document.getElementById(id);

  if (!input.dataset.customStarted) {
    input.dataset.customStarted = "true";
    input.value = "#808080";
  }

  previewTransition(state);
}

function setDelay(value) {
  document.getElementById("delayInput").value = value;
  previewTransition("config");
}

function setEco() {
  document.getElementById("brightnessInput").value = 60;
  previewTransition("config");
}

function setBrightnessNormal() {
  document.getElementById("brightnessInput").value = 150;
  previewTransition("config");
}

let previewTimeout = null;

function previewTransition(state = "config") {
  clearTimeout(previewTimeout);

  previewTimeout = setTimeout(() => {
    const form = document.getElementById("configForm");
    const data = new FormData(form);
    data.append("previewState", state);

    fetch("/preview", {
      method: "POST",
      body: data
    }).catch(() => {});
  }, 150);
}
</script>

</body>
</html>
)rawliteral";

  html.replace("%IDLE_COLOR%", colorToHex(COLOR_IDLE));
  html.replace("%WORK_COLOR%", colorToHex(COLOR_WORK));
  html.replace("%BREAK_COLOR%", colorToHex(COLOR_BREAK));
  html.replace("%CONFIG_COLOR%", colorToHex(COLOR_CONFIG));

  html.replace("%WORK_MIN%", String(constrain(workMs / 60000UL, 1UL, 99UL)));
  html.replace("%BREAK_MIN%", String(constrain(breakMs / 60000UL, 1UL, 99UL)));
  html.replace("%IDLE_MIN%", String(constrain(idleLedMs / 60000UL, 1UL, 99UL)));

  html.replace("%DELAY%", String(transitionDelayMs));
  html.replace("%BRIGHTNESS%", String(brightness));

  html.replace("%T0%", transition == SET_RING ? "selected" : "");
  html.replace("%T1%", transition == RUNNING_LIGHT ? "selected" : "");
  html.replace("%T2%", transition == RUNNING_FILL ? "selected" : "");
  html.replace("%T3%", transition == RUNNING_LIGHT_CLEAR ? "selected" : "");
  html.replace("%T4%", transition == FADE ? "selected" : "");

  return html;
}

void handleRoot() {
  server.send(200, "text/html", htmlPage());
}

void handleSave() {
  COLOR_IDLE = hexToColor(server.arg("idleColor"));
  COLOR_WORK = hexToColor(server.arg("workColor"));
  COLOR_BREAK = hexToColor(server.arg("breakColor"));
  COLOR_CONFIG = hexToColor(server.arg("configColor"));

  workMs = constrain(server.arg("workMin").toInt(), 1, 99) * 60UL * 1000UL;
  breakMs = constrain(server.arg("breakMin").toInt(), 1, 99) * 60UL * 1000UL;
  idleLedMs = constrain(server.arg("idleMin").toInt(), 1, 99) * 60UL * 1000UL;

  transition = (Transition)server.arg("transition").toInt();
  transitionDelayMs = constrain(server.arg("delay").toInt(), 5, 500);
  brightness = constrain(server.arg("brightness").toInt(), 5, 255);

  saveSettings();
  applyTransition(COLOR_CONFIG);

  server.sendHeader("Location", "/");
  server.send(303);
}

void handleReset() {
  resetSettings();
  applyTransition(COLOR_CONFIG);

  server.sendHeader("Location", "/");
  server.send(303);
}

void handlePreview() {
  if (server.hasArg("brightness")) {
    brightness = constrain(server.arg("brightness").toInt(), 5, 255);
  }

  if (server.hasArg("delay")) {
    transitionDelayMs = constrain(server.arg("delay").toInt(), 5, 500);
  }

  if (server.hasArg("transition")) {
    transition = (Transition)server.arg("transition").toInt();
  }

  if (server.hasArg("idleColor")) COLOR_IDLE = hexToColor(server.arg("idleColor"));
  if (server.hasArg("workColor")) COLOR_WORK = hexToColor(server.arg("workColor"));
  if (server.hasArg("breakColor")) COLOR_BREAK = hexToColor(server.arg("breakColor"));
  if (server.hasArg("configColor")) COLOR_CONFIG = hexToColor(server.arg("configColor"));

  String previewState = server.arg("previewState");

  if (previewState == "idle") {
    applyTransition(COLOR_IDLE);
  }
  else if (previewState == "work") {
    applyTransition(COLOR_WORK);
  }
  else if (previewState == "break") {
    applyTransition(COLOR_BREAK);
  }
  else {
    applyTransition(COLOR_CONFIG);
  }

  server.send(200, "text/plain", "OK");
}

void handleCaptivePortal() {
  server.sendHeader("Location", "http://10.10.10.1", true);
  server.send(302, "text/plain", "");
}

// --- Config server control ---
void startConfigServer() {
  rainbowMode = false;
  configMode = true;

  WiFi.mode(WIFI_AP);
  WiFi.softAPConfig(apIP, gateway, subnet);
  WiFi.softAP(AP_SSID, AP_PASS);

  dnsServer.start(53, "*", apIP);
  MDNS.begin("pomodesk");

  server.on("/", handleRoot);
  server.on("/save", HTTP_POST, handleSave);
  server.on("/reset", HTTP_POST, handleReset);
  server.on("/preview", HTTP_POST, handlePreview);
  server.on("/exit", HTTP_GET, handleExitConfig);
  server.on("/sleep", HTTP_GET, handleSleep);
  server.onNotFound(handleCaptivePortal);

  server.begin();

  applyTransition(COLOR_CONFIG);
}
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
void loop() {
  delay(5);

  button.update();

  if (configMode) {
    dnsServer.processNextRequest();
    server.handleClient();
    return;
  }

  if (rainbowMode) {
    updateRainbowCycle();
    return;
  }

  uint32_t now = millis();

  if (state == WORK && now - stateStartMs >= workMs) {
    enterState(BREAK);
  }
  else if (state == BREAK && now - stateStartMs >= breakMs) {
    enterState(IDLE);
  }
  else if (state == IDLE && !idleLedsOff && now - stateStartMs >= idleLedMs) {
    allLedsOff();
    idleLedsOff = true;
  }
}

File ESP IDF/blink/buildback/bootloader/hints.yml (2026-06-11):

#  -
#     re: Regular expression of error to search
#     hint: The message of the hint. Optionally, it is possible to use '{}' at the place where the matched group from 're' should be inserted. This requires 'match_to_output: True'. You can use variables with hint messages. For this, you need to add variables and "{}" in a place where you want to put your hint variable, but you can't use 'match_to_output' with variables.
#     match_to_output: (False by default) see the description of 'hint'.
#     variables:
#       -
#           re_variables: [set variable for regular expression]
#           hint_variables: [set variable for hint]
# Rules to write regex for hints on how to resolve errors
# - Do not use more than one whitespace in a row. The script automatically merges several whitespaces into one when capturing output
# - Do not use \n in your regex. They are all automatically deletes by the script when capturing output
#
# example of using hints:
#    -
#        re: "Error: header {} is missing" (you can use '{1} ... {1}' placeholders in 'hint' and 're', so that you don't have to repeat the same variables, you can use 'hint: 'The {0} (functions/types/macros prefixed with '{1}') has been made into a private API. If users still require usage of the {0} (though this is not recommended), it can be included via  #include "esp_private/{2}.h".' in this file as an example)
#        hint: "header {} is missing, you need to add dependency on component {}"
#        variables:
#            -
#               re_variables: [Q]
#               hint_variables: [A, B]
#            -
#               re_variables: [W]
#               hint_variables: [C, D]
#            -
#               re_variables: [R]
#               hint_variables: [E, F]
#
#   that example will replace this :
#   -
#       re: "Error: header Q is missing"
#       hint: "header A is missing, you need to add dependency on component B"
#   -
#       re: Error: header W is missing"
#       hint: "header C is missing, you need to add dependency on component D"
#   -
#       re: Error: header R is missing"
#       hint: "header E is missing, you need to add dependency on component F"

-
    re: "warning: passing argument 1 of 'esp_secure_boot_read_key_digests' from incompatible pointer type"
    hint: "The parameter type of the function esp_secure_boot_read_key_digests() has been changed from ets_secure_boot_key_digests_t* to esp_secure_boot_key_digests_t*."

-
    re: "error: implicit declaration of function '{}'"
    hint: "Function '{}' has been removed. Please use the function {}."
    variables:
        -
            re_variables: ['bootloader_common_get_reset_reason']
            hint_variables: ['bootloader_common_get_reset_reason()', "'esp_rom_get_reset_reason()' in the ROM component"]
        -
            re_variables: ['esp_efuse_get_chip_ver']
            hint_variables: ['esp_efuse_get_chip_ver()', 'efuse_hal_get_major_chip_version()', 'efuse_hal_get_minor_chip_version() or efuse_hal_chip_revision() instead']
        -
            re_variables: ['(esp_spiram_get_chip_size|esp_spiram_get_size)']
            hint_variables: ['esp_spiram_get_chip_size and esp_spiram_get_size', 'esp_psram_get_size()']
        -
            re_variables: ['sdm_channel_set_duty']
            hint_variables: ['sdm_channel_set_duty()', 'sdm_channel_set_pulse_density()']

-
    re: "error: implicit declaration of function '(MCPWM_GEN_TIMER_EVENT_ACTION_END|MCPWM_GEN_COMPARE_EVENT_ACTION_END|MCPWM_GEN_BRAKE_EVENT_ACTION_END)'"
    hint: "Macro function '{}()' has been removed. Please don't use variadic APIs when setting MCPWM generator actions."
    match_to_output: True

-
    re: "error: implicit declaration of function 'esp_secure_boot_verify_rsa_signature_block'"
    hint: "'esp_secure_boot_verify_rsa_signature_block()' has been made private and is no longer available."

-
    re: "error: implicit declaration of function '{}'"
    hint: '{0}.h header file is not included by esp_system.h anymore. It shall then be manually included with #include "{0}.h"'
    variables:
        -
            re_variables: ['(esp_random|esp_fill_random)']
            hint_variables: ['esp_random']
        -
            re_variables: ['(esp_base_mac_addr_(s|g)et|esp_efuse_mac_get_(custom|default)|esp_read_mac|esp_derive_local_mac)']
            hint_variables: ['esp_mac']
        -
            re_variables: ['esp_chip_info']
            hint_variables: ['esp_chip_info']

-
    re: "fatal error: (spiram.h|esp_spiram.h): No such file or directory"
    hint: "{} was removed. Include esp_psram.h instead. Make sure to also add esp_psram as a dependency in your CMakeLists.txt file."
    match_to_output: True
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

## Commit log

2026-05-16 pcb 3d file
2026-05-18 update after initial tests
    [pomo-desk-bottom-v4.stl, pomo-desk-top-v4.stl]
2026-05-20 added long-press to turn off leds, and added fade-out/in transition
2026-06-10 raindbow state if held for 3 seconds. 6 seconds for power down.
